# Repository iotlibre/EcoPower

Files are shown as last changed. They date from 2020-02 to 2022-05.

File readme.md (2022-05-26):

# EcoPower

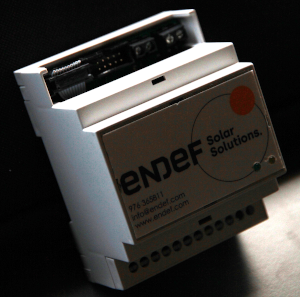
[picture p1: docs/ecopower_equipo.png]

Ecopower está pensado para tomar las medidas de consumo eléctrico de una vivienda o de un edificio con consumos inferiores a 30 KW. El sistema permite diferenciar varias zonas.

EcoPower se puede instalar en el cuadro eléctrico principal o en cualquier otra parte que nos permita tomar datos del consumo mediante pinzas (transformadores de intensidad).

En el un edificio podemos tener tantos dispositivos como sean necesarios y el servidor los integrará en la misma instalación sin necesidad de configuraciones adicionales o cambios en el Firmware.

La comunicación se hace mediante Wifi por lo que no es necesario el cableado de datos al equipo solamente es preciso que esté dentro de la cobertura de la red WIFI del edificio.

Para su uso no son necesarios conocimientos de informática aunque todos los desarrollos y el hardware están hechos bajo licencias libres lo que permite la modificación y mejora de las funcionalidades.

## Listado con las principales características
Las principales características de EcoPower son:
- 6 entradas para sensores de corriente con salida estandar de 50 mA
- 1 entrada de medida de voltage 200 - 440 Voltios
- Precisión en las medida de energía: ± 1,2%
- Comunicación a Internet por WIFI local 
- Configurable vía Web
- Estandard: IEEE 802.11 b/g/n
- Alimentación a 220 voltios de corriente alterna. Rango: 85 ~ 264VAC 
- Montaje en carril din
- La PCB integra un Arduino nano con el ESP8266 12E
- Compatible con el [servidor de Open Energy Monitor](https://emoncms.org/)

## Puesta a punto
La puesta a punto de EcoPower consta de dos partes:
- La configuración en la instalación
- El firmware de Arduino

### La configuración en la instalación
En este punto se definen los parámetros del servidor de destino y la wifi local a la que va a estar conectado el dispositivo. Con este fin, la primera vez que se ponga en servicio el ESP y siempre que no encuentre la WIFI configurada, el ESP 8266 12E creará su propio punto de acceso, su propia red WIFI . Conectandose a cualquier dirección a través de este punto de acceso nos aparecerá la página de configuración del ESP. Tengase en cuenta que una  vez configurado el ESP y conectado a una red WIFI el router le asignará una única dirección IP a la que será necesario acceder para cambiar la configuración.

En caso de que se quiera actualizar el firmware del ESP a la última versión, este se puede encontrar en: [EcoPower-emonESP ](https://github.com/iotlibre/20180328_EmonESP)

### El firmware de Arduino
El firmware que que esta cargado por defecto en el arduino nano funciona correctamente para tranformadores de intensidad de 100A/50mA sin embargo, si quiere cambiar la configuración puede encontrar la última actualización del firmware en este repositorio:[EcoPower-iotpow_serial ](https://github.com/iotlibre/EcoPower/tree/master/firmware/iotpower_serial/iotpow_serial)

## Source code
Copyright 2020 Endef Engineering SL.

Tanto el hardware como el software de este repositorio han sido desarrollados por la empresa: [Endef Engineering Sl](https://endef.com)

## Licencia
* Los diseños de hardware estan disponibles bajo licencia "Creative Commons Attribution-ShareAlike 3.0 Unported License.".
* El firmware se publica bajo la licencia GNU GPL V3 La documentación está sujeta a la Licencia "GNU Free Documentation"
* Los diseños de hardware siguen los términos de la Declaración de principios 1.0 de OSHW (Open-source hardware).

## Disclaimer
Todo el código que se encuentra en este repositorio está bajo la licencia: "GNU V3 General Public License" por lo que las condiciones de su uso son las incluidas en esta licencia

NUESTROS PRODUCTOS Y JUEGOS DE MONTAJE PUEDEN SER UTILIZADOS POR USUARIOS EXPERIMENTADOS Y CAPACITADOS BAJO SU PROPIO RIESGO. EN LA MEDIDA MÁXIMA QUE LO PERMITA LA LEY APLICABLE, POR EL PRESENTE RENUNCIAMOS CUALQUIER RESPONSABILIDAD, RIESGO Y DAÑOS DERIVADOS DE LA MUERTE O LESIONES PERSONALES RESULTANTES DEL MONTAJE O FUNCIONAMIENTO DE NUESTROS PRODUCTOS.

Su seguridad es su propia responsabilidad, incluido el uso adecuado del equipo y el equipo de seguridad, y determinar si tiene la habilidad y la experiencia adecuadas. Endef Engineering se exime de toda responsabilidad por cualquier daño, lesión o gasto resultante. Es su responsabilidad asegurarse de que sus actividades cumplan con las leyes aplicables, incluidos los derechos de autor. Puede haber actualizaciones o correcciones importantes. Todo uso de las instrucciones, kits, proyectos y sugerencias dadas por Endef Ingeniería es bajo su propio riesgo. La tecnología (hardware, firmware y software) cambia constantemente, es posible que la documentación (incluidas las instrucciones y la guía de compilación) no esté completa o sea correcta.

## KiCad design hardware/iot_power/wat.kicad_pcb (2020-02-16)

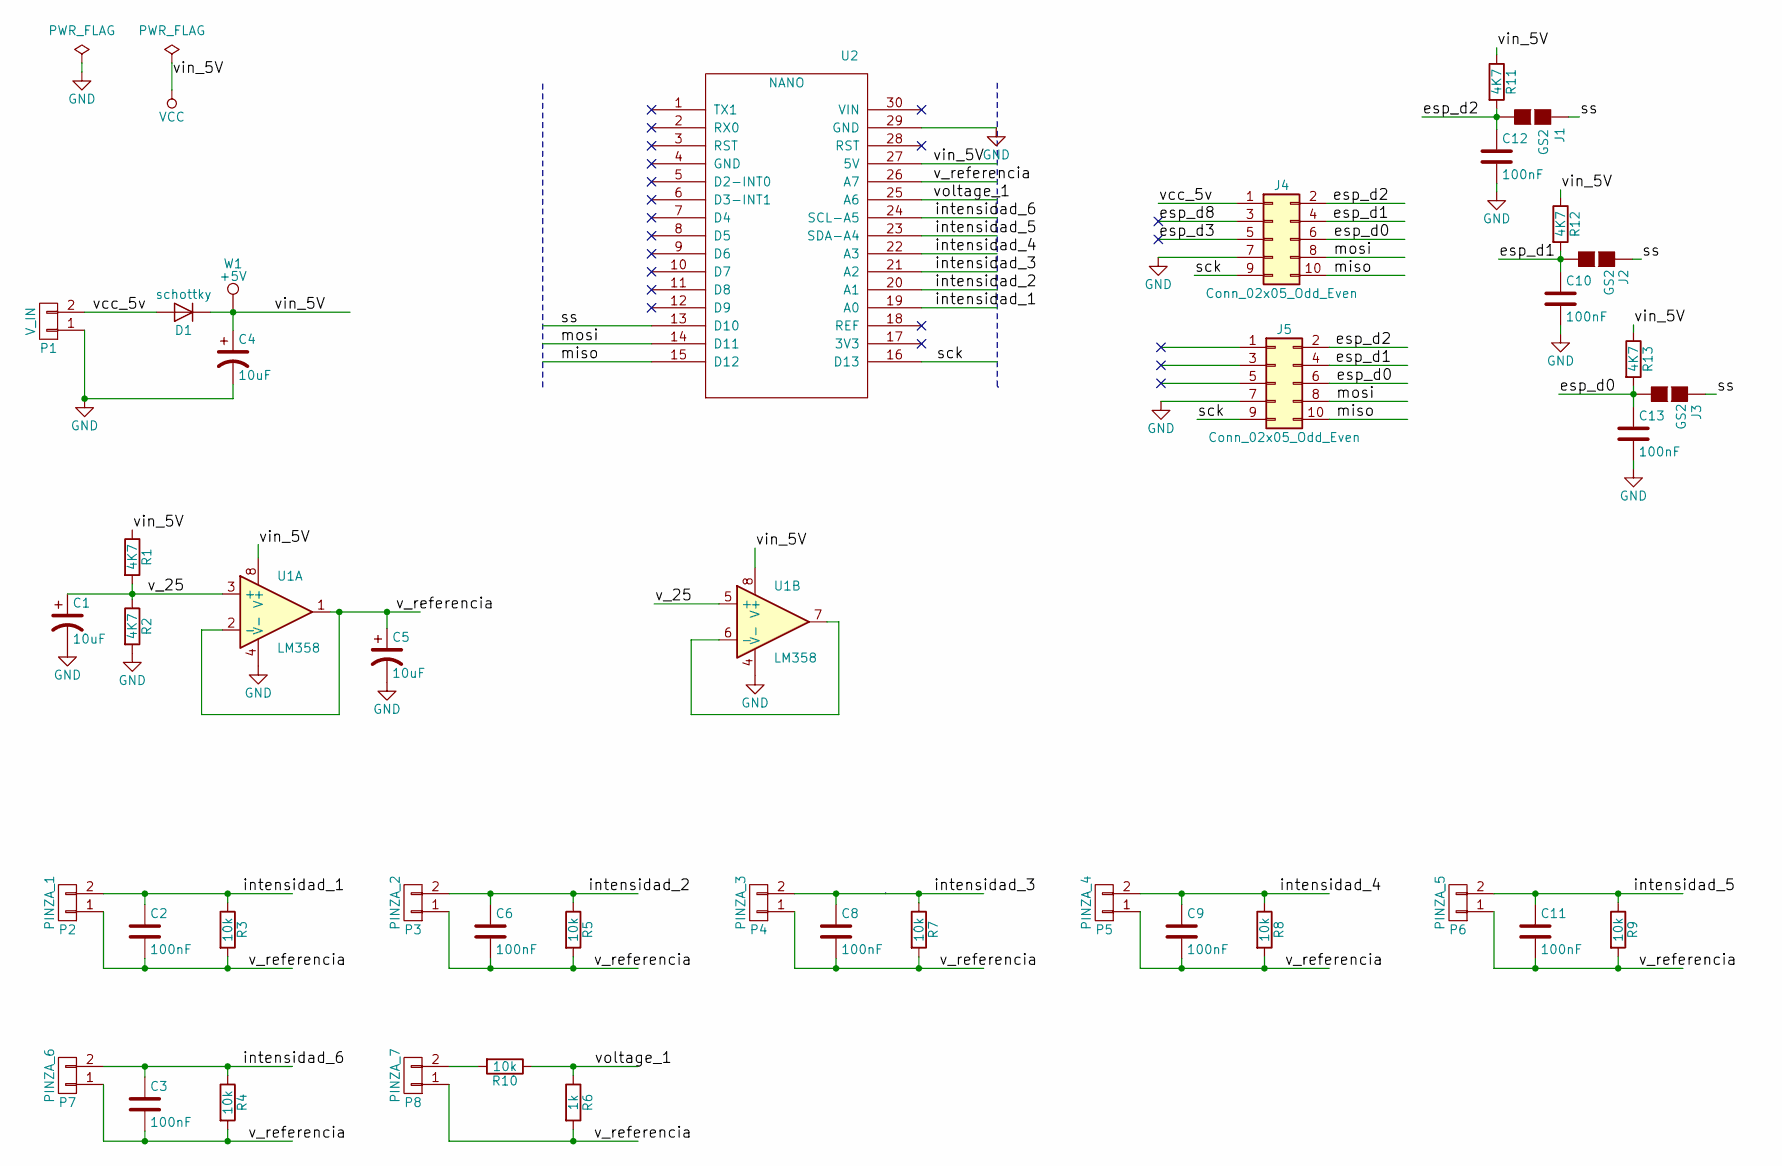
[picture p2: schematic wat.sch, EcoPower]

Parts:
C1, C4, C5: 10uF; C_2220_HandSoldering
C2, C3, C6, C8, C9, C10, C11, C12, C13: 100nF; C_1206_HandSoldering
D1: schottky; D_2114
J1, J2, J3: GS2
J4, J5: Conn_02x05_Odd_Even; Pin_Header_Straight_2x05_Pitch2.54mm_onsar
P1: V_IN; TerminalBlock_bornier-2_P5.08mm
P2: PINZA_1; TerminalBlock_bornier-2_P5.08mm
P3: PINZA_2; TerminalBlock_bornier-2_P5.08mm
P4: PINZA_3; TerminalBlock_bornier-2_P5.08mm
P5: PINZA_4; TerminalBlock_bornier-2_P5.08mm
P6: PINZA_5; TerminalBlock_bornier-2_P5.08mm
P7: PINZA_6; TerminalBlock_bornier-2_P5.08mm
P8: PINZA_7; TerminalBlock_bornier-2_P5.08mm
R1, R2, R11, R12, R13: 4K7; R_1206_HandSoldering
R3, R4, R5, R7, R8, R9: 10k; Resistor_Horizontal_RM10mm
R6: 1k; Resistor_Horizontal_RM10mm
R10: 10k; R_1206_HandSoldering
U1: LM358; SO-8_5.3x6.2mm_Pitch1.27mm
U2: NANO; arduino_nano
W1: +5V; SolderWirePad_single_0-8mmDrill

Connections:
/esp_d0: C13.1, J3.2 (G2), J4.6, J5.6, R13.2
/esp_d1: C10.1, J2.2 (G2), J4.4, J5.4, R12.2
/esp_d2: C12.1, J1.2 (G2), J4.2, J5.2, R11.2
/esp_d3: J4.5
/esp_d8: J4.3
/intensidad_1: C2.1, P2.2, R3.1, U2.19 (A0)
/intensidad_2: C6.1, P3.2, R5.1, U2.20 (A1)
/intensidad_3: C8.1, P4.2, R7.1, U2.21 (A2)
/intensidad_4: C9.1, P5.2, R8.1, U2.22 (A3)
/intensidad_5: C11.1, P6.2, R9.1, U2.23 (SDA-A4)
/intensidad_6: C3.1, P7.2, R4.1, U2.24 (SCL-A5)
/miso: J4.10, J5.10, U2.15 (D12)
/mosi: J4.8, J5.8, U2.14 (D11)
/sck: J4.9, J5.9, U2.16 (D13)
/ss: J1.1 (G1), J2.1 (G1), J3.1 (G1), U2.13 (D10)
/v_25: C1.1, R1.2, R2.1, U1.3 (+), U1.5 (+)
/v_referencia: C2.2, C3.2, C5.1, C6.2, C8.2, C9.2, C11.2, P2.1, P3.1, P4.1, P5.1, P6.1, P7.1, P8.1, R3.2, R4.2, R5.2, R6.2, R7.2, R8.2, R9.2, U1.1, U1.2 (-), U2.26 (A7)
/vcc_5v: D1.2 (A), J4.1, P1.2
/voltage_1: R6.1, R10.1, U2.25 (A6)
GND: C1.2, C4.2, C5.2, C10.2, C12.2, C13.2, J4.7, J5.7, P1.1, R2.2, U1.4 (V-), U2.29 (GND)
unnamed: P8.2, R10.2
unnamed: U1.6 (-), U1.7
VCC: C4.1, D1.1 (K), R1.1, R11.1, R12.1, R13.1, U1.8 (V+), U2.27 (5V), W1.1

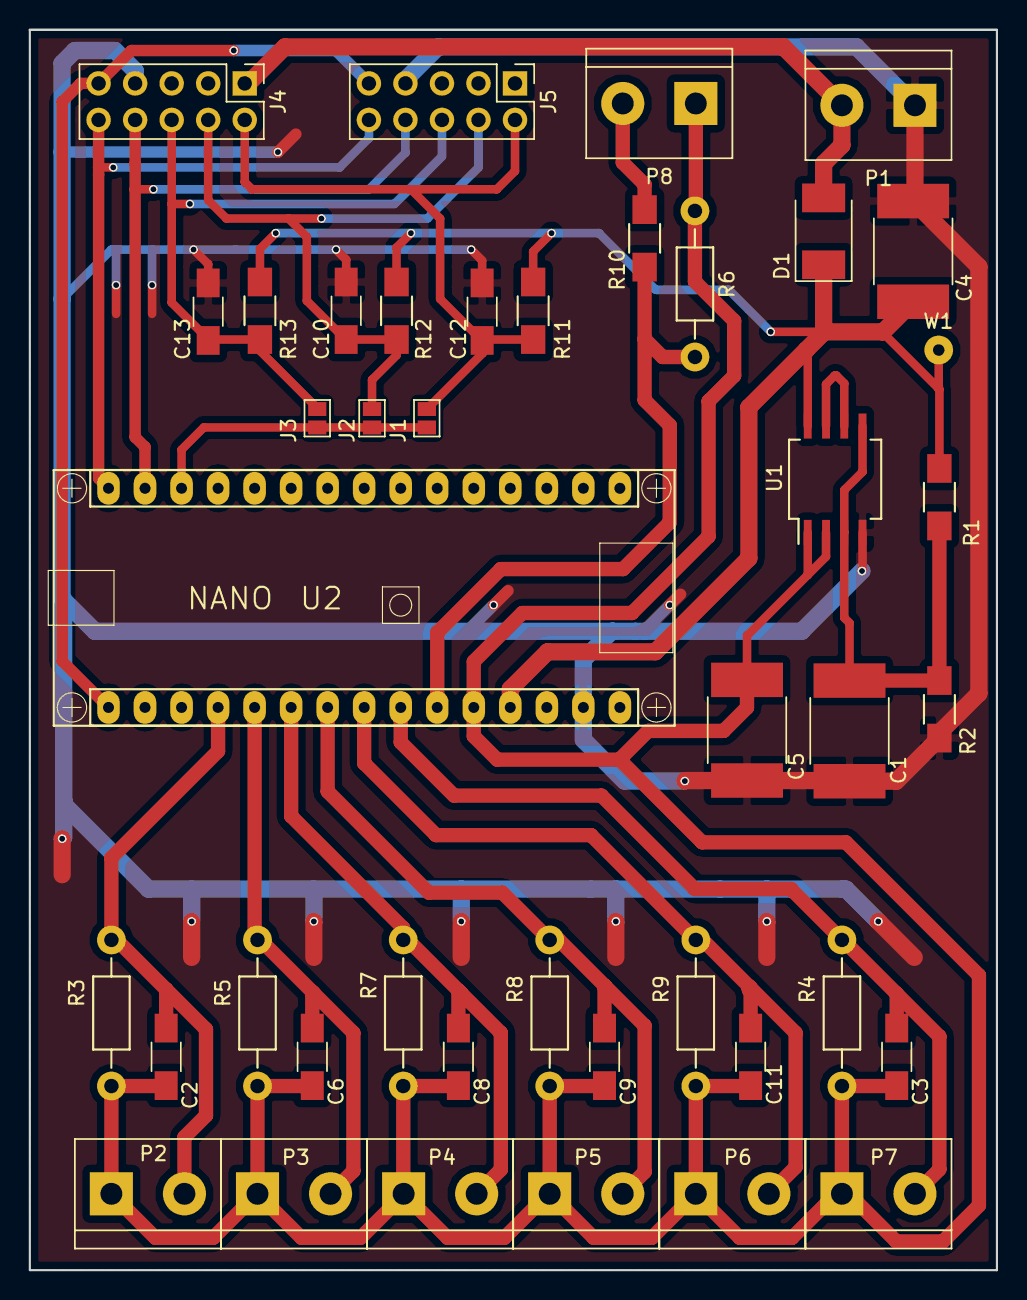
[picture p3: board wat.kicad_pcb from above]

Board: 2 copper layers, 67.2 x 86.2 mm, 42 parts (0 on the bottom side), 21 nets.

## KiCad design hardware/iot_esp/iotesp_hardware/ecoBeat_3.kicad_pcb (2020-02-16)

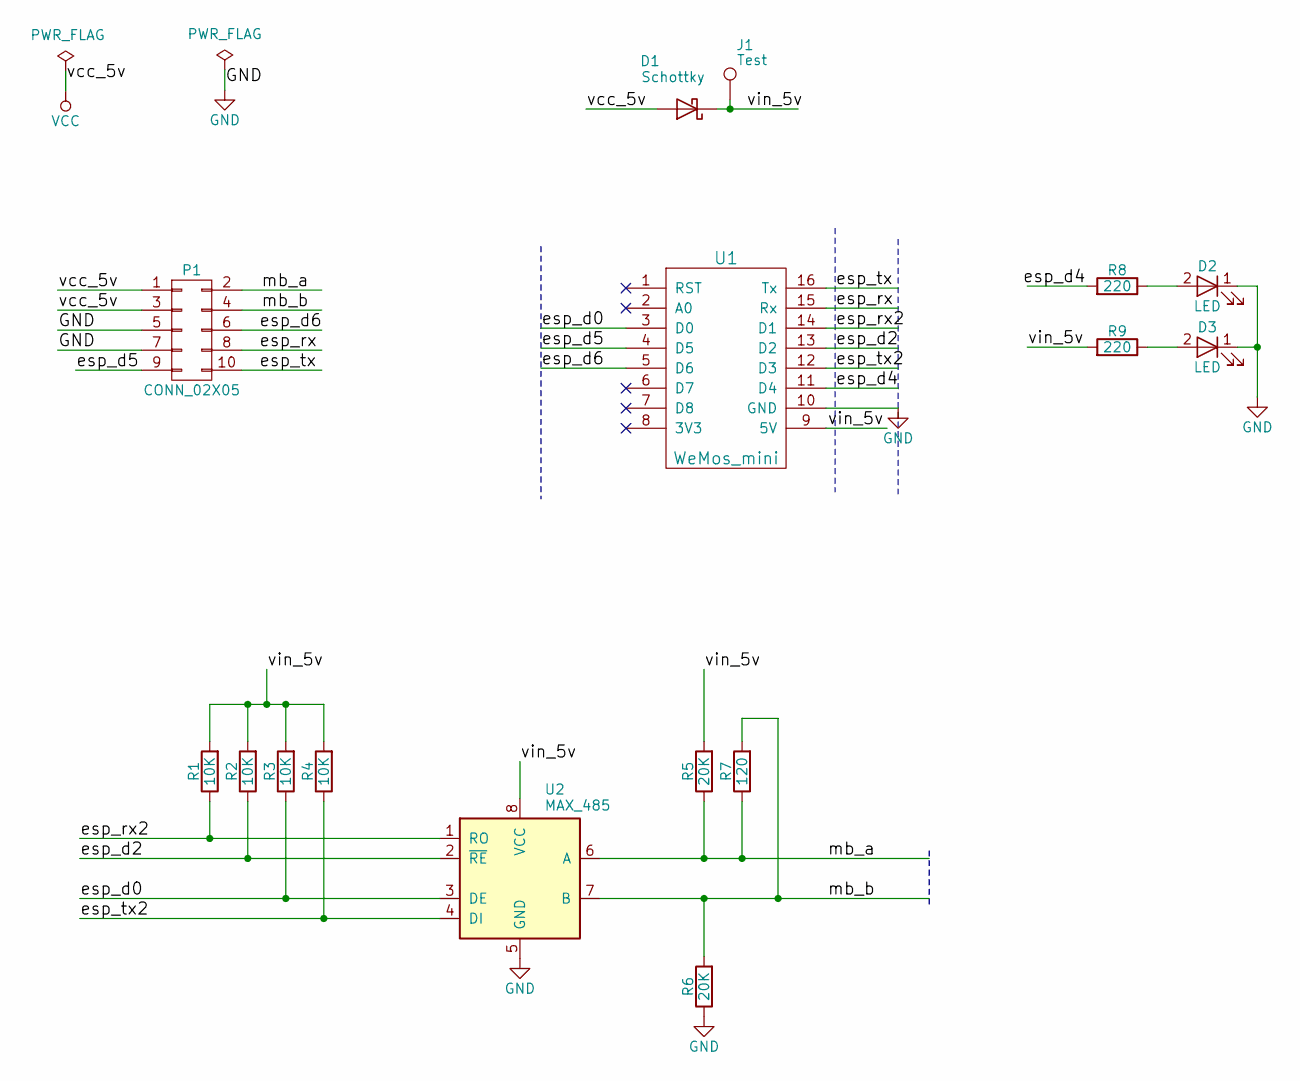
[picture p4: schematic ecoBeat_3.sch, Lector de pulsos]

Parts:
D1: Schottky; D_2114
D2, D3: LED; LED_D3.0mm
J1: Test; SolderWirePad_single_0-8mmDrill
P1: CONN_02X05; D1_mini_board
R1, R2, R3, R4: 10K; R_1206_HandSoldering
R5, R6: 20K; R_1206_HandSoldering
R7: 120; R_1206_HandSoldering
R8, R9: 220; R_1206_HandSoldering
U1: WeMos_mini; D1_mini_board_oscar
U2: MAX_485; SOIC-8-N

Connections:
/esp_d0: R3.1, U1.3 (D0), U2.3 (DE)
/esp_d2: R2.1, U1.13 (D2), U2.2 (~RE~)
/esp_d4: R8.2, U1.11 (D4)
/esp_d5: P1.9, U1.4 (D5)
/esp_d6: P1.6, U1.5 (D6)
/esp_rx: P1.8, U1.15 (Rx)
/esp_rx2: R1.1, U1.14 (D1), U2.1 (RO)
/esp_tx: P1.10, U1.16 (Tx)
/esp_tx2: R4.1, U1.12 (D3), U2.4 (DI)
/mb_a: P1.2, R5.1, R7.1, U2.6 (A)
/mb_b: P1.4, R6.2, R7.2, U2.7 (B)
/vin_5v: D1.1 (K), J1.1, R1.2, R2.2, R3.2, R4.2, R5.2, R9.2, U1.9 (5V), U2.8 (VCC)
GND: D2.1 (K), D3.1 (K), P1.5, P1.7, R6.1, U1.10 (GND), U2.5 (GND)
unnamed: D2.2 (A), R8.1
unnamed: D3.2 (A), R9.1
VCC: D1.2 (A), P1.1, P1.3

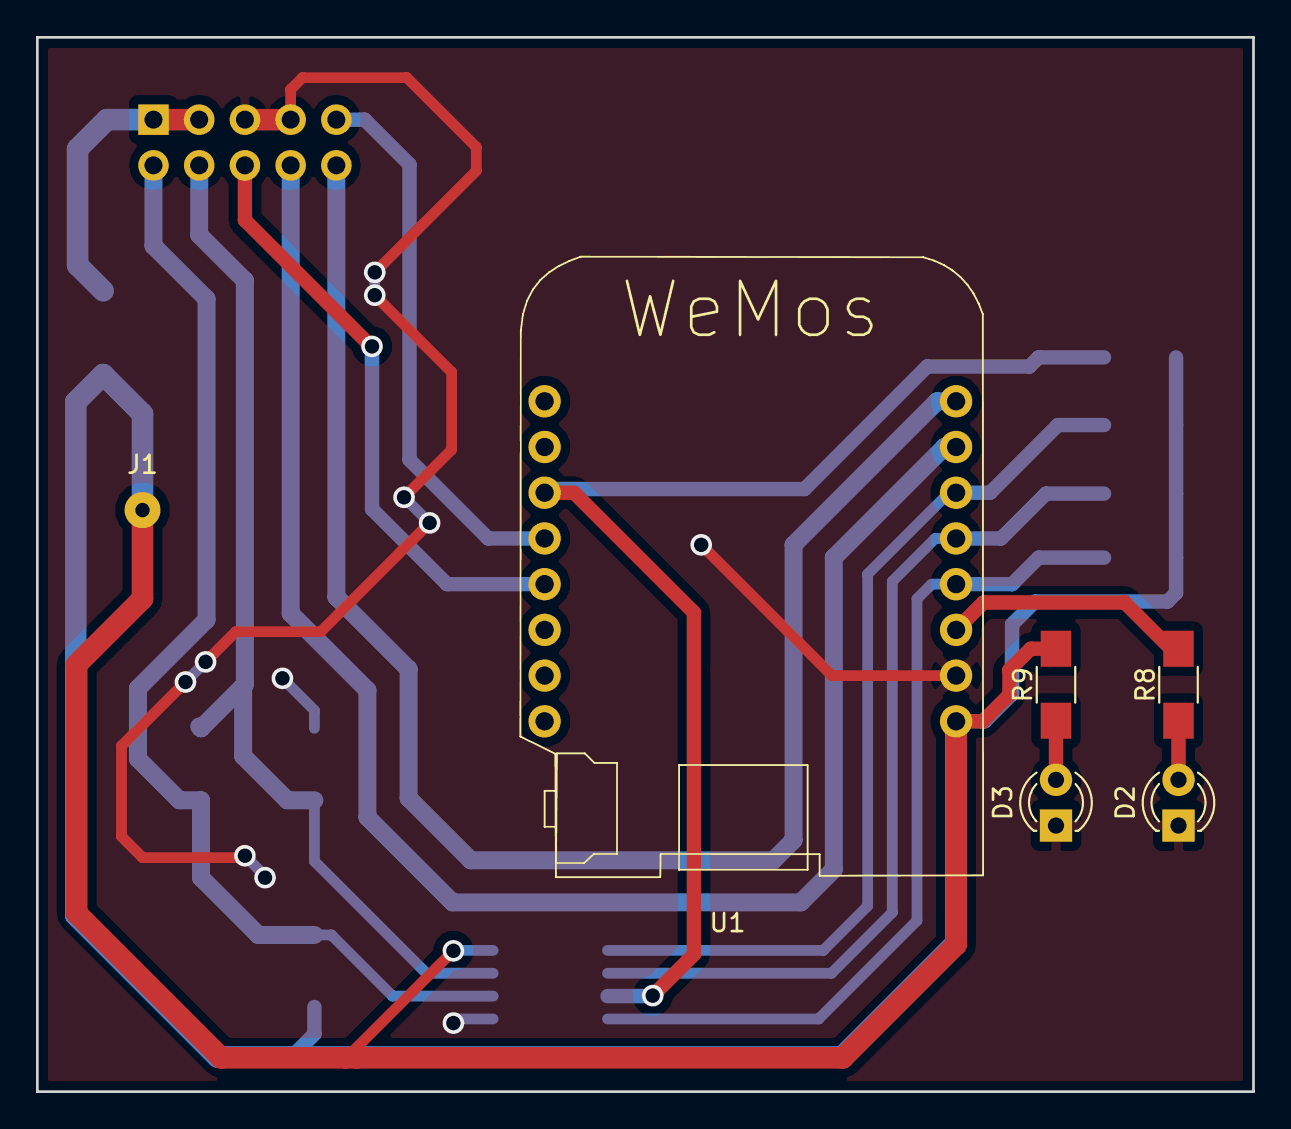
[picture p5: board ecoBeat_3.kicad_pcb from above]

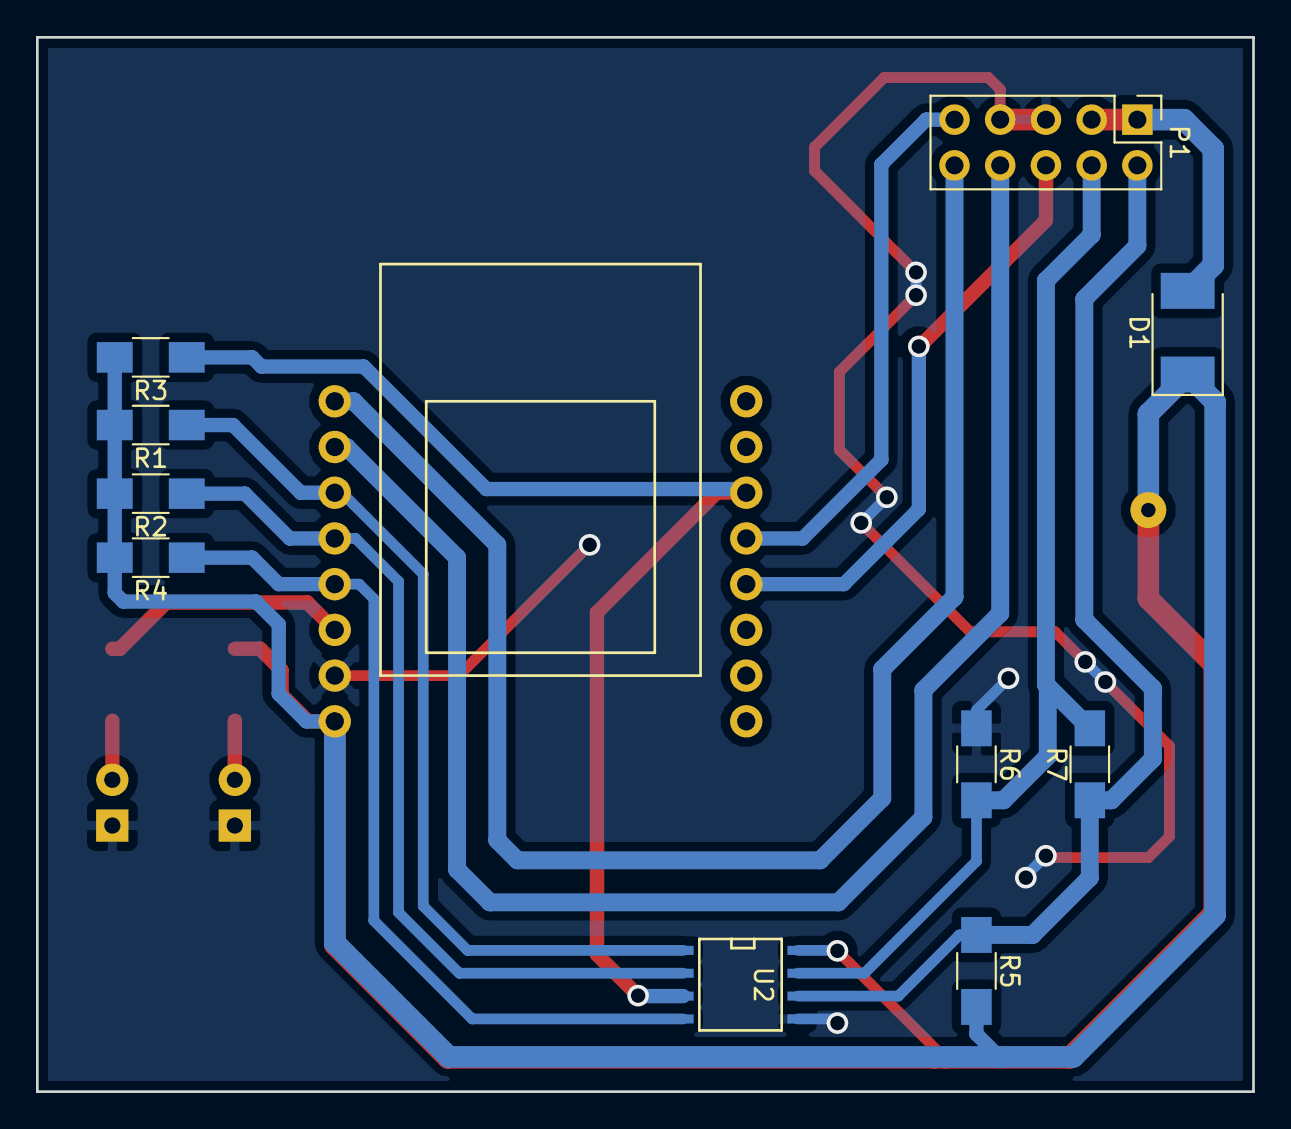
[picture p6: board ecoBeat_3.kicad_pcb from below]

Board: 2 copper layers, 67.6 x 58.6 mm, 16 parts (10 on the bottom side), 16 nets.

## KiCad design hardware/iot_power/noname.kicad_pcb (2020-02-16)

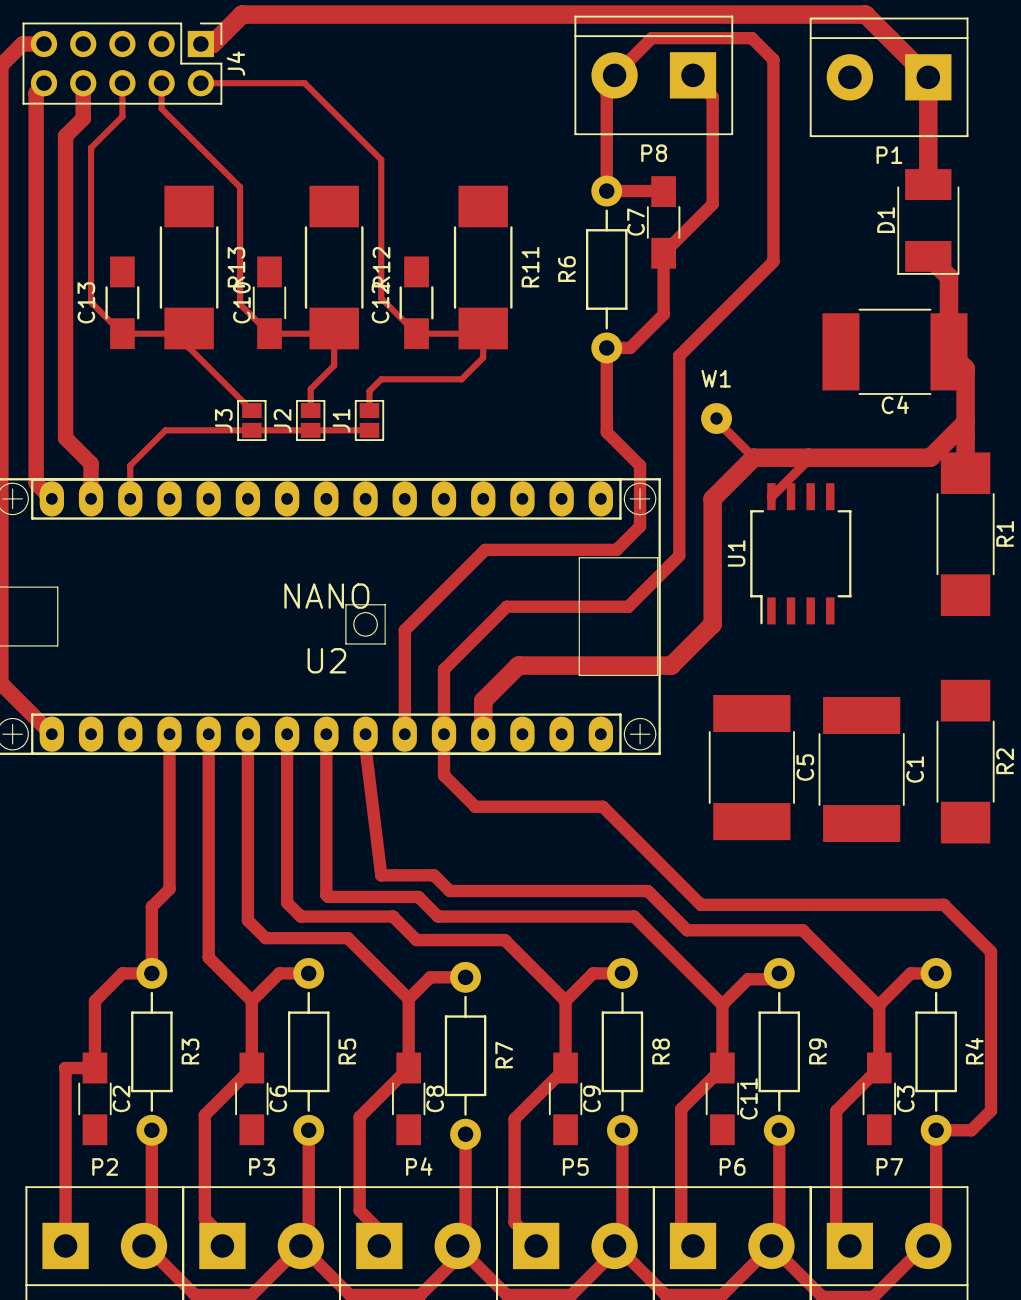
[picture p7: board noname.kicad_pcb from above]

Board: 2 copper layers, 41 parts (0 on the bottom side), 19 nets.

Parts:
C1, C4, C5: 10uF; C_2220_HandSoldering
C2, C3, C6, C7, C8, C9, C10, C11, C12, C13: 100nF; C_1206_HandSoldering
D1: schottky; D_2114
J1, J2, J3: GS2
J4: Conn_02x05_Odd_Even; Pin_Header_Straight_2x05_Pitch2.54mm
P1: V_IN; TerminalBlock_bornier-2_P5.08mm
P2: PINZA_1; TerminalBlock_bornier-2_P5.08mm
P3: PINZA_2; TerminalBlock_bornier-2_P5.08mm
P4: PINZA_3; TerminalBlock_bornier-2_P5.08mm
P5: PINZA_4; TerminalBlock_bornier-2_P5.08mm
P6: PINZA_5; TerminalBlock_bornier-2_P5.08mm
P7: PINZA_6; TerminalBlock_bornier-2_P5.08mm
P8: PINZA_7; TerminalBlock_bornier-2_P5.08mm
R1, R2, R11, R12, R13: 4K7; R_2512_HandSoldering
R3, R4, R5, R6, R7, R8, R9: 10k; Resistor_Horizontal_RM10mm
U1: LM358; SO-8_5.3x6.2mm_Pitch1.27mm
U2: NANO; arduino_nano
W1: +5V; SolderWirePad_single_0-8mmDrill

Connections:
/esp_d0: C13.1, J3.2, J4.6, R13.2
/esp_d1: C10.1, J2.2, J4.4, R12.2
/esp_d2: C12.1, J1.2, J4.2, R11.2
/intensidad_1: C2.1, P2.1, R3.1, U2.19
/intensidad_2: C6.1, P3.1, R5.1, U2.20
/intensidad_3: C8.1, P4.1, R7.1, U2.21
/intensidad_4: C9.1, P5.1, R8.1, U2.22
/intensidad_5: C11.1, P6.1, R9.1, U2.23
/intensidad_6: C3.1, P7.1, R4.1, U2.24
/intensidad_7: C7.1, P8.1, R6.1, U2.25
/miso: J4.10, U2.15
/mosi: J4.8, U2.14
/sck: J4.9, U2.16
/ss: J1.1, J2.1, J3.1, U2.13
/v_referencia: C2.2, C3.2, C5.1, C6.2, C7.2, C8.2, C9.2, C11.2, P2.2, P3.2, P4.2, P5.2, P6.2, P7.2, P8.2, R3.2, R4.2, R5.2, R6.2, R7.2, R8.2, R9.2, U1.1, U1.2, U2.26
/vcc_5v: D1.2, J4.1, P1.1
GND: C1.2, C4.2, C5.2, C10.2, C12.2, C13.2, J4.7, P1.2, R2.2, U1.4, U2.29
unnamed: C1.1, R1.2, R2.1, U1.3
VCC: C4.1, D1.1, R1.1, R11.1, R12.1, R13.1, U1.8, U2.27, W1.1

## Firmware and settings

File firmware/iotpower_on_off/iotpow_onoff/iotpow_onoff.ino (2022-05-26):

/*
This program is free software: you can redistribute it and/or modify
it under the terms of the GNU General Public License as published by
the Free Software Foundation, either version 3 of the License, or
(at your option) any later version.
This program is distributed in the hope that it will be useful,
but WITHOUT ANY WARRANTY; without even the implied warranty of
MERCHANTABILITY or FITNESS FOR A PARTICULAR PURPOSE. See the
GNU General Public License for more details.
You should have received a copy of the GNU General Public License
along with this program. If not, see <http://www.gnu.org/licenses/>. 
*/


/*

Sketchbook location
/home/onsar/git/onsar/ecopower/firmware/iotpower_serial/iotpow_serial


*/



#define DEBUG 0

#define BPS 115200 //Velocidad de las comunicaciones

#ifdef DEBUG == 1
  int freeRam(){
    extern int __heap_start, *__brkval;
    int v;
    return (int) &v - (__brkval == 0 ? (int) &__heap_start : (int) __brkval);
  }
#endif

/*
#include <SoftwareSerial.h>
#define RXPIN 6
#define TXPIN 5
SoftwareSerial wifiSerialInit (RXPIN,TXPIN);
*/

/* D12 MISO  -> e_rx (D5)
 * D11 MOSI  -> e_tx (D6)
 */




#include <SoftwareSerial.h>
#define RXPIN 12    //11
#define TXPIN 11    //12
SoftwareSerial wifiSerialInit (RXPIN,TXPIN);


#include "power_onoff_sensor.h"

uint32_t t_last_tx=0;
uint32_t t_last_measurement=0;

void setup(void){     
  Serial.begin(BPS);
  wifiSerialInit.begin(BPS);
  configure_output();
}

void loop(void){

  uint32_t current_time= millis();

  // en prevision de que el contador de tiempo de la vuelta
  if (current_time < t_last_tx) t_last_tx=0; 
  if (current_time - t_last_tx > 59000){  
    t_last_tx = current_time;
    if(DEBUG){
      Serial.print(F("******Print LCD - sgs: "));
      Serial.println(millis() / 1000);
      Serial.print("freeRam: "); Serial.println(freeRam());   
      Serial.flush();    
    }
    buildPowerMessage(0);
  }
  
  // en prevision de que el contador de tiempo de la vuelta
  if (current_time < t_last_measurement) t_last_measurement=0;
  // Medida de potencia cada 200ms
  if (current_time - t_last_measurement > 200){     
    t_last_measurement = current_time;
    calculate_power();
    }
  }
  

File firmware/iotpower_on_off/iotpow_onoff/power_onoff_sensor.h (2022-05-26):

/*
This program is free software: you can redistribute it and/or modify
it under the terms of the GNU General Public License as published by
the Free Software Foundation, either version 3 of the License, or
(at your option) any later version.
This program is distributed in the hope that it will be useful,
but WITHOUT ANY WARRANTY; without even the implied warranty of
MERCHANTABILITY or FITNESS FOR A PARTICULAR PURPOSE. See the
GNU General Public License for more details.
You should have received a copy of the GNU General Public License
along with this program. If not, see <http://www.gnu.org/licenses/>. 
*/

#ifndef power_sensor_h
#define power_sensor_h

// *******************************************************
// ******** CONFIGURACION SENSORES DE POTENCIA    ********
// *******************************************************

// 97.6  66.5  51.3(39.0 ohm)  20.0 (100.0 ohm)

#define NUMBER_OF_PWR_SENSORS 4
#define TRANSFORMATOR_CONSTANT 24

#define MAME_PWR_1 "s1"
#define ENTER_1 A0
#define CURRENT_CONST_1 TRANSFORMATOR_CONSTANT

#define MAME_PWR_2 "s2"
#define ENTER_2 A1
#define CURRENT_CONST_2 TRANSFORMATOR_CONSTANT

#define MAME_PWR_3 "s3"
#define ENTER_3 A2
#define CURRENT_CONST_3 TRANSFORMATOR_CONSTANT

#define MAME_PWR_4 "s4"
#define ENTER_4 A3
#define CURRENT_CONST_4 TRANSFORMATOR_CONSTANT

#define MAME_PWR_5 "p5"
#define ENTER_5 A4
#define CURRENT_CONST_5 TRANSFORMATOR_CONSTANT

#define MAME_PWR_6 "p6"
#define ENTER_6 A5
#define CURRENT_CONST_6 TRANSFORMATOR_CONSTANT

#define MAME_PWR_7 "v1"
#define ENTER_7 A6
#define CURRENT_CONST_7 180.2


// Falta la medida del voltage

// *******************************************************

#include "EmonLib.h"                   // Include Emon Library
EnergyMonitor emon1;

/*
// variable declaration
// long 2,147,483,647 (with sing)
// 240 x 100 x 60 seg x 5 medias
// 7,200,000
*/

typedef struct {                                                      // RFM RF payload datastructure
  String name_input;
  int pin_input;
  float constant_input;
  long power_sum;
  long power_measurements;
} analog_input;

analog_input p1={MAME_PWR_1,ENTER_1,CURRENT_CONST_1,0,0};
analog_input p2={MAME_PWR_2,ENTER_2,CURRENT_CONST_2,0,0};
analog_input p3={MAME_PWR_3,ENTER_3,CURRENT_CONST_3,0,0};
analog_input p4={MAME_PWR_4,ENTER_4,CURRENT_CONST_4,0,0};
analog_input p5={MAME_PWR_5,ENTER_5,CURRENT_CONST_5,0,0};
analog_input p6={MAME_PWR_6,ENTER_6,CURRENT_CONST_6,0,0};
analog_input v1={MAME_PWR_7,ENTER_7,CURRENT_CONST_7,0,0};


analog_input analog_inputs[]={p1,p2,p3,p4,p5,p6,v1};


// Function Prototypes
void configure_output();
void calculate_power();
void buildPowerMessage(uint8_t);

/* 
 *  configurar las salidas auxiliares para medir tiempos
 *  en los que un relé esta activo
*/
void configure_output(){ 
  pinMode(analog_inputs[4].pin_input, OUTPUT); 
  digitalWrite(analog_inputs[4].pin_input, LOW);
  pinMode(analog_inputs[5].pin_input, OUTPUT); 
  digitalWrite(analog_inputs[5].pin_input, LOW);
}

void calculate_power(){

  // uint32_t millis_init =millis();
 
  emon1.current(analog_inputs[6].pin_input,analog_inputs[6].constant_input); // calibration.
  double Vrms = emon1.calcIrms(141);  // Calculate Irms only, (119 20ms for algoritm )
  // Serial.println(millis()-millis_init);
  if(Vrms < 40) Vrms = 1;  // para evitar numeros muy elevados
  analog_inputs[6].power_sum+= Vrms; 
  analog_inputs[6].power_measurements++ ;    

  

  
  // millis_init =millis();
  for (uint8_t i=0; i < NUMBER_OF_PWR_SENSORS; i++){     
    emon1.current(analog_inputs[i].pin_input,analog_inputs[i].constant_input); // calibration.
    double Irms = emon1.calcIrms(141);  // Calculate Irms only, (119 20ms for algoritm )
    analog_inputs[i].power_sum+=(Irms*Vrms); 
    analog_inputs[i].power_measurements++ ;    
  }
  // Serial.println(millis()-millis_init);
}

void buildPowerMessage(uint8_t output){
  uint32_t millis_init =millis();
  for (uint8_t i=0; i < NUMBER_OF_PWR_SENSORS; i++){ 
    long power_result = analog_inputs[i].power_sum/analog_inputs[i].power_measurements;     
    if (output==0){
      if(DEBUG){
        Serial.print ("name_input: ");          Serial.println(analog_inputs[i].name_input);       
        Serial.print ("power_sum: ");           Serial.println (analog_inputs[i].power_sum); 
        Serial.print ("power_measurements: ");  Serial.println (analog_inputs[i].power_measurements);
        Serial.println (analog_inputs[i].name_input+ ":" + power_result); 
        Serial.flush();     
      }
      wifiSerialInit.println (analog_inputs[i].name_input+ ":" + power_result);
      analog_inputs[i].power_sum = 0;
      analog_inputs[i].power_measurements = 0;
      
    }
  }
  if(DEBUG){Serial.println(millis()-millis_init);}
}

#endif

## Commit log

2020-02-16 primera versión de produccion
    [ecoBeat_3-B.CrtYd.gbr, ecoBeat_3-B.Cu.gbr, ecoBeat_3-B.Fab.gbr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]
2020-02-16 edicion de readme
2020-02-16 Parámetros principales de EcoPower
2020-02-20 facto de tension para transformadors Vac, factor de corriente para transformadores 400 0.1
2020-02-23 priemera varsion para medir tiempos de rele
2020-02-23 iotpower_onoff. version de producción
2020-03-02 constante transformador 8V
